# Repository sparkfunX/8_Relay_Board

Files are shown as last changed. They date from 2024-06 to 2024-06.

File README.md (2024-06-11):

SparkX 8 Relay Control Board
========================================

8 Relay Control Board (https://www.sparkfun.com/products/24475)

[*8 Relay Control Board (SPX-24475)*](https://www.sparkfun.com/products/24475)

A simple breakout for controlling 8 relays with logic level signals. Each relay channel is opto-isolated from its corresponding logic input, the inputs accept both 3V and 5V logic, and a status LED on each channel makes it easy to tell at a glance which relay is energized. All LEDs on the board, including the power indicator, are connected through cuttable solder jumpers so they can be disabled if you don't need them. The relays are rated to 5A/250VAC, making them useful for a lot of power control applications.

Repository Contents
-------------------

* **/Hardware** - Eagle design files (.brd, .sch)
* **/Production** - Production panel files (.brd)

License Information
-------------------

This product is _**open source**_! 

Please review the LICENSE.md file for license information. 

If you have any questions or concerns on licensing, please contact technical support on our [SparkFun forums](https://forum.sparkfun.com/viewforum.php?f=152).

Distributed as-is; no warranty is given.

- Your friends at SparkFun.

_<COLLABORATION CREDIT>_

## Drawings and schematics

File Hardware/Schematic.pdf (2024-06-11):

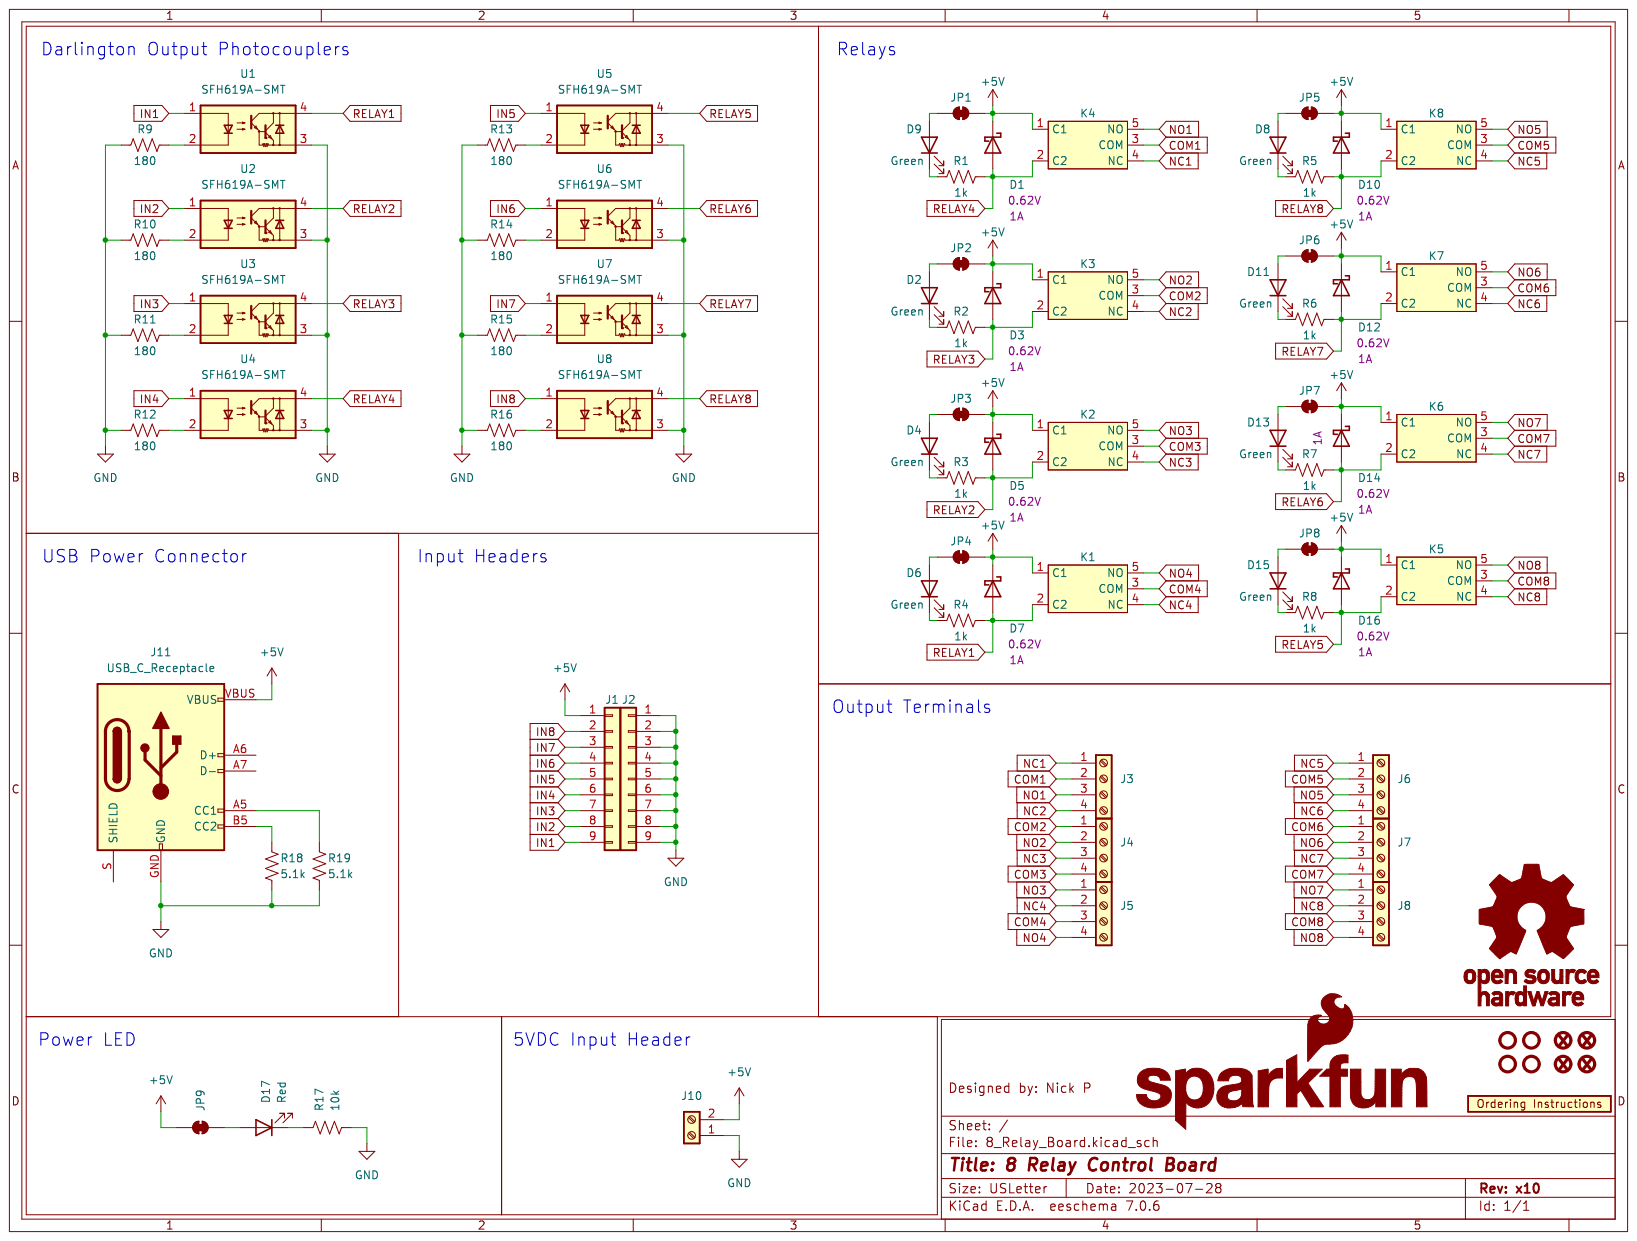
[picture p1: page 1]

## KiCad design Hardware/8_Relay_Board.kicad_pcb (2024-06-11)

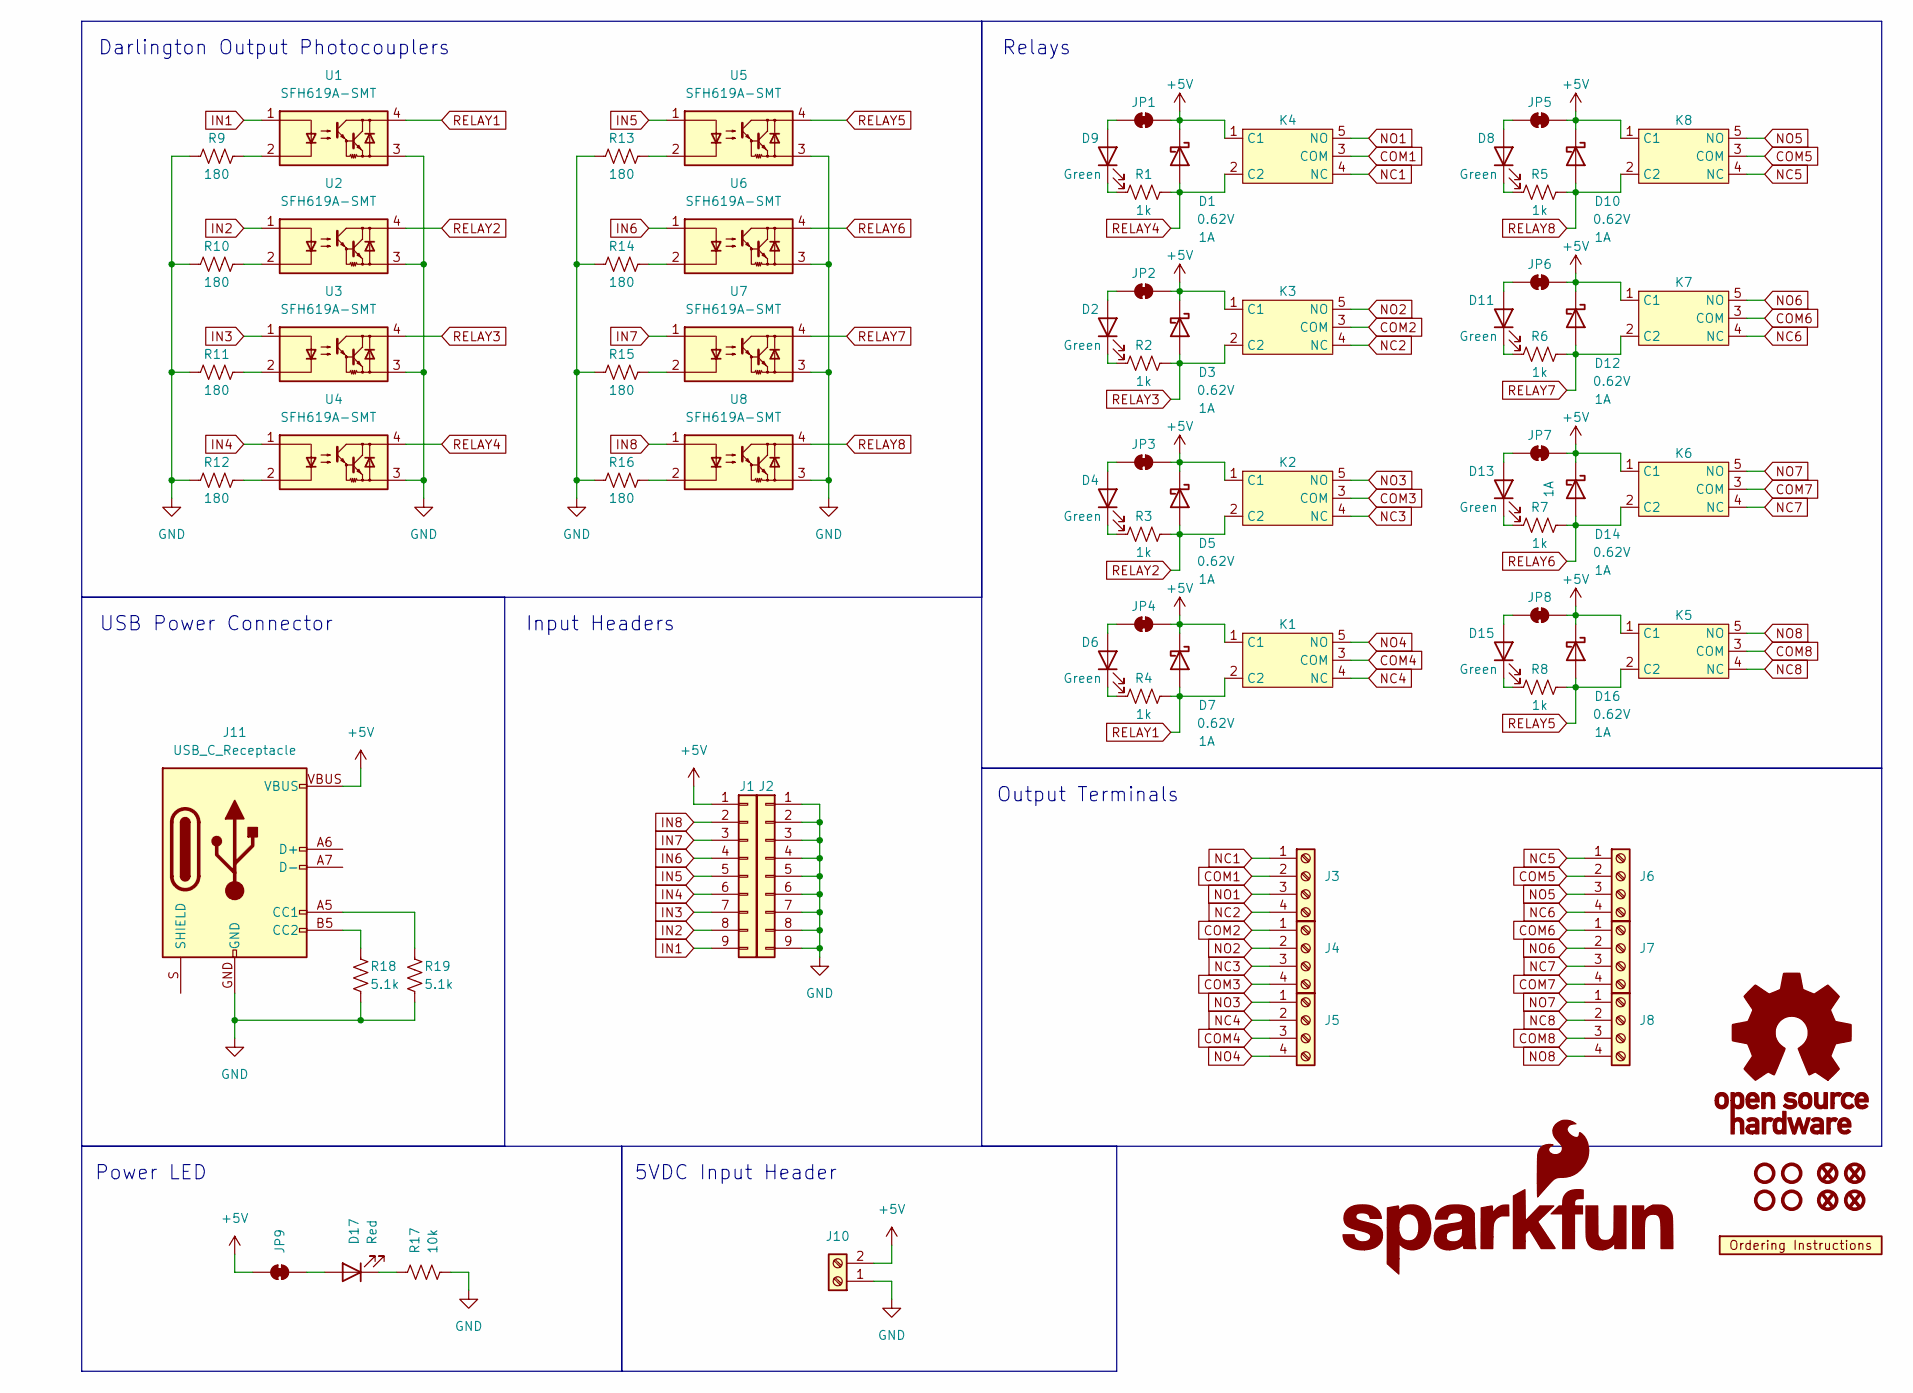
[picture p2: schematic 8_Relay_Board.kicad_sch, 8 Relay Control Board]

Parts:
D1, D3, D5, D7, D10, D12, D16: D_Schottky_1A_23V_0.62V; SOD-323
D2, D4, D6, D8, D9, D11, D13, D15: Green; LED_0603_1608Metric
D14: D_Schottky_1A_23V_0.62V; SOD-323; Reverse Voltage 23V
D17: Red; LED_0603_1608Metric
FID1, FID2, FID3, FID4: Fiducial_0.5; Fiducial_0.5mm_Mask1mm
G1: OSHW_Logo; Creative_Commons_License
G5: SparkFun_Logo; SparkFun_Logo_8mm
J1, J2: Conn_01x09; 1X09
J3, J4, J5, J6, J7, J8: Screw_Terminal_3.5mm_4; SCREWTERMINAL-3.5MM-4
J10: Screw_Terminal_3.5mm_2; SCREWTERMINAL-3.5MM-2
J11: USB_C_Receptacle; USB-C-16P
JP1, JP2, JP3, JP4, JP5, JP6, JP7, JP8, JP9: SMT-JUMPER_2_NC_TRACE_SILK
K1, K2, K3, K4, K5, K6, K7, K8: RELAY-JZC-11F
R1, R2, R3, R4, R5, R6, R7, R8: 1k; R_0603_1608Metric
R9, R10, R11, R12, R13, R14, R15, R16: 180; R_0603_1608Metric
R17: 10k; R_0603_1608Metric
R18, R19: 5.1k; R_0603_1608Metric
ST1, ST2, ST3, ST4: Stand_off; STAND-OFF
U1, U2, U3, U4, U5, U6, U7, U8: SFH619A-SMT; SMDIP4-WIDE
U9: ORDERING_INSTRUCTIONS

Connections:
+5V: D1.C, D3.C, D5.C, D7.C, D10.C, D12.C, D14.C, D16.C, J1.1, J10.2, J11.VBUS, JP1.2 (B), JP2.2 (B), JP3.2 (B), JP4.2 (B), JP5.2 (B), JP6.2 (B), JP7.2 (B), JP8.2 (B), JP9.2 (B), K1.1 (C1), K2.1 (C1), K3.1 (C1), K4.1 (C1), K5.1 (C1), K6.1 (C1), K7.1 (C1), K8.1 (C1)
COM1: J3.2, K4.3 (COM)
COM2: J4.1, K3.3 (COM)
COM3: J4.4, K2.3 (COM)
COM4: J5.3, K1.3 (COM)
COM5: J6.2, K8.3 (COM)
COM6: J7.1, K7.3 (COM)
COM7: J7.4, K6.3 (COM)
COM8: J8.3, K5.3 (COM)
GND: J2.1, J2.2, J2.3, J2.4, J2.5, J2.6, J2.7, J2.8, J2.9, J10.1, J11.GND, R9.1, R10.1, R11.1, R12.1, R13.1, R14.1, R15.1, R16.1, R17.2, R18.2, R19.2, U1.3, U2.3, U3.3, U4.3, U5.3, U6.3, U7.3, U8.3
IN1: J1.9, U1.1
IN2: J1.8, U2.1
IN3: J1.7, U3.1
IN4: J1.6, U4.1
IN5: J1.5, U5.1
IN6: J1.4, U6.1
IN7: J1.3, U7.1
IN8: J1.2, U8.1
NC1: J3.1, K4.4 (NC)
NC2: J3.4, K3.4 (NC)
NC3: J4.3, K2.4 (NC)
NC4: J5.2, K1.4 (NC)
NC5: J6.1, K8.4 (NC)
NC6: J6.4, K7.4 (NC)
NC7: J7.3, K6.4 (NC)
NC8: J8.2, K5.4 (NC)
NO1: J3.3, K4.5 (NO)
NO2: J4.2, K3.5 (NO)
NO3: J5.1, K2.5 (NO)
NO4: J5.4, K1.5 (NO)
NO5: J6.3, K8.5 (NO)
NO6: J7.2, K7.5 (NO)
NO7: J8.1, K6.5 (NO)
NO8: J8.4, K5.5 (NO)
unnamed: D2.2 (A), JP2.1 (A)
unnamed: D2.1 (K), R2.1
unnamed: D4.2 (A), JP3.1 (A)
unnamed: D4.1 (K), R3.1
unnamed: D6.2 (A), JP4.1 (A)
unnamed: D6.1 (K), R4.1
unnamed: D8.2 (A), JP5.1 (A)
unnamed: D8.1 (K), R5.1
unnamed: D9.2 (A), JP1.1 (A)
unnamed: D9.1 (K), R1.1
unnamed: D11.2 (A), JP6.1 (A)
unnamed: D11.1 (K), R6.1
unnamed: D13.2 (A), JP7.1 (A)
unnamed: D13.1 (K), R7.1
unnamed: D15.2 (A), JP8.1 (A)
unnamed: D15.1 (K), R8.1
unnamed: D17.2 (A), JP9.1 (A)
unnamed: D17.1 (K), R17.1
unnamed: J11.A5 (CC1), R19.1
unnamed: J11.B5 (CC2), R18.1
unnamed: J11.A6 (D+), J11.B6 (D+)
unnamed: J11.A7 (D-), J11.B7 (D-)
unnamed: R9.2, U1.2
unnamed: R10.2, U2.2
unnamed: R11.2, U3.2
unnamed: R12.2, U4.2
unnamed: R13.2, U5.2
unnamed: R14.2, U6.2
unnamed: R15.2, U7.2
unnamed: R16.2, U8.2
RELAY1: D7.A, K1.2 (C2), R4.2, U1.4
RELAY2: D5.A, K2.2 (C2), R3.2, U2.4
RELAY3: D3.A, K3.2 (C2), R2.2, U3.4
RELAY4: D1.A, K4.2 (C2), R1.2, U4.4
RELAY5: D16.A, K5.2 (C2), R8.2, U5.4
RELAY6: D14.A, K6.2 (C2), R7.2, U6.4
RELAY7: D12.A, K7.2 (C2), R6.2, U7.4
RELAY8: D10.A, K8.2 (C2), R5.2, U8.4

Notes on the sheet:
Relays
USB Power Connector
Output Terminals
Input Headers
5VDC Input Header
Power LED
Darlington Output Photocouplers

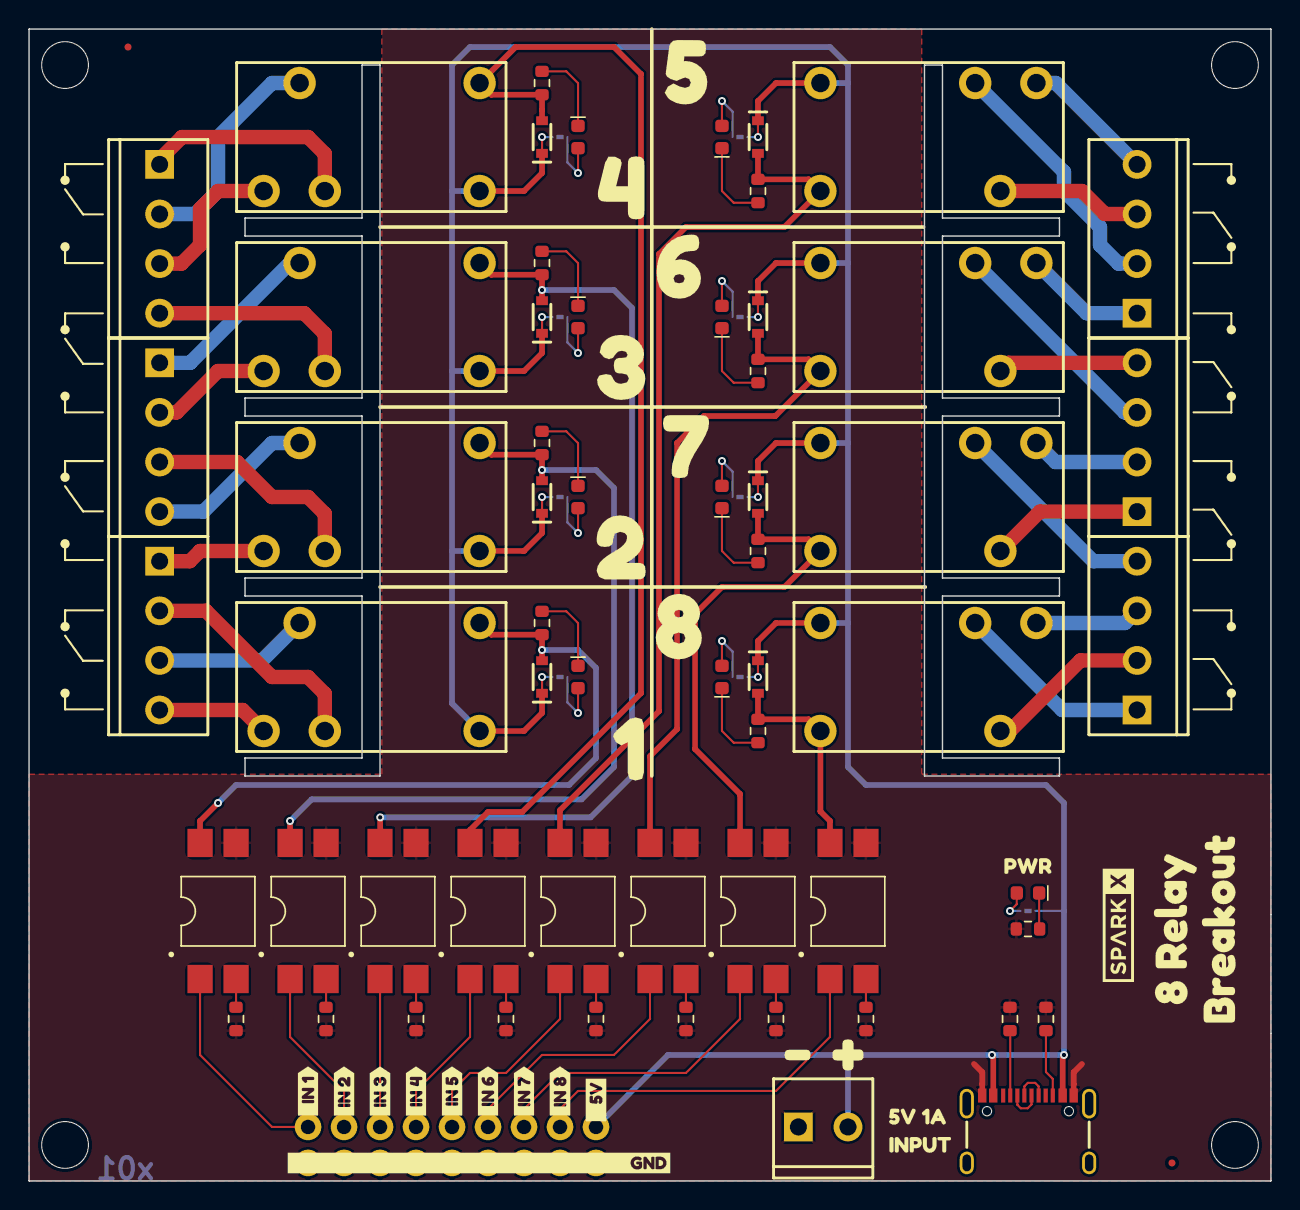
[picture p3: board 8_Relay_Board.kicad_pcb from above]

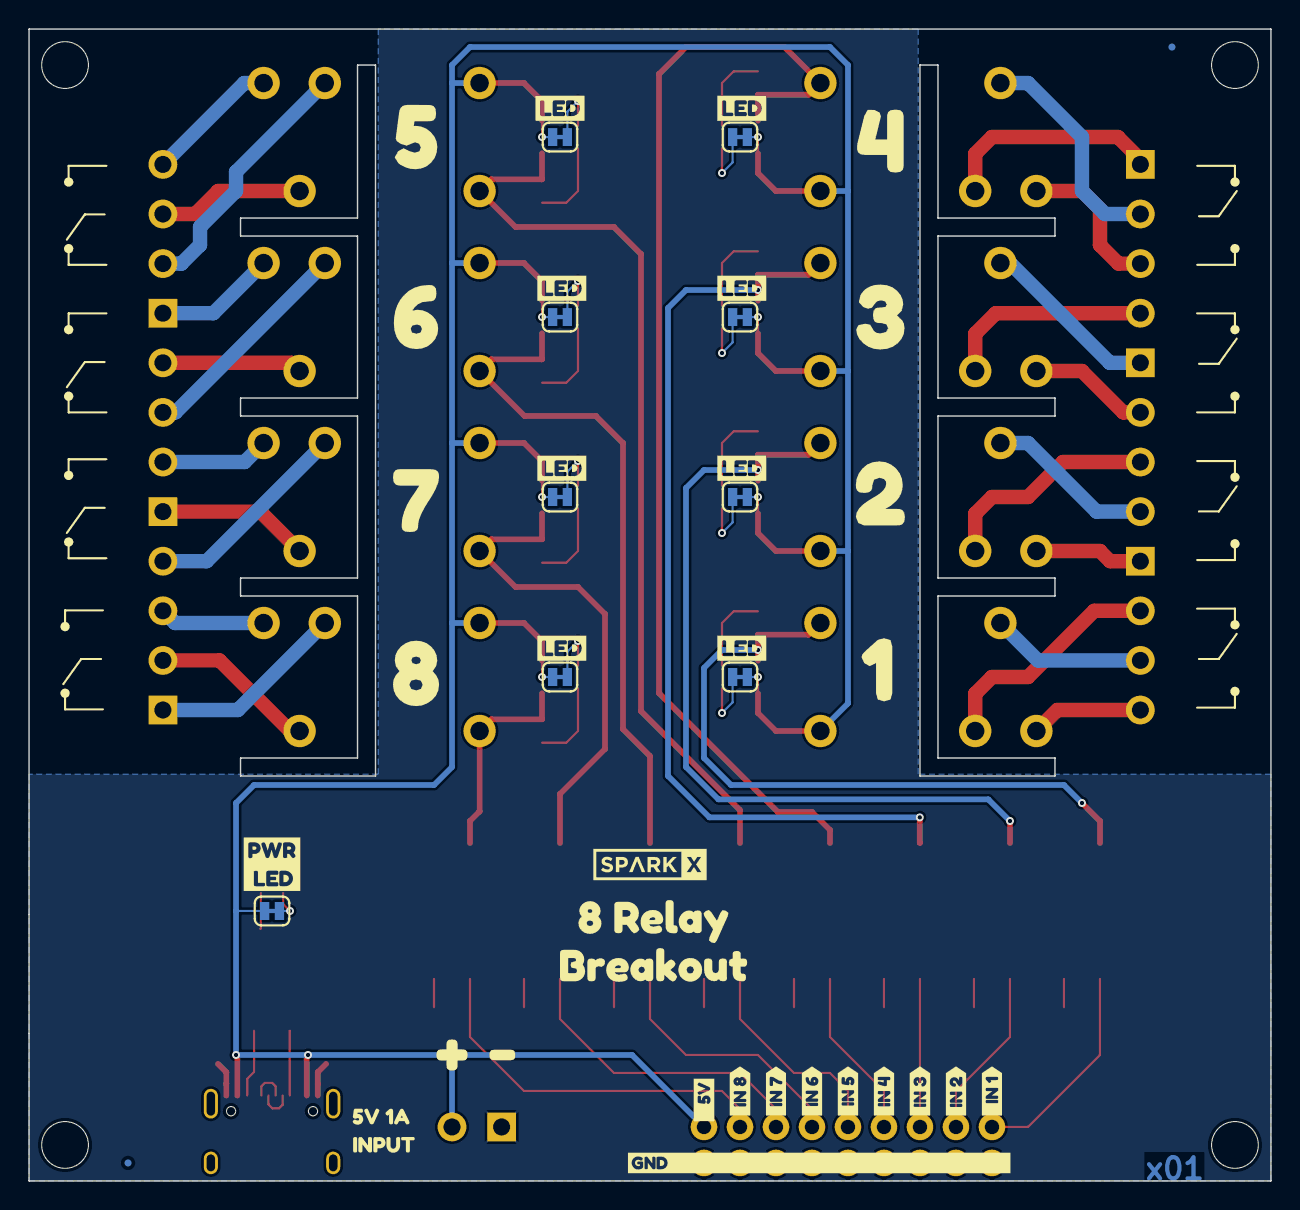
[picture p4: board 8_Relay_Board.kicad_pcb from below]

Board: 4 copper layers, 87.6 x 81.3 mm, 137 parts (43 on the bottom side), 72 nets.

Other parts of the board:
kibuzzard-652EF88E: G***; kibuzzard-652EF88E
kibuzzard-652EF841: G***; kibuzzard-652EF841
kibuzzard-652EF889: G***; kibuzzard-652EF889
kibuzzard-65656C10: G***; kibuzzard-65656C10
kibuzzard-65656C50: G***; kibuzzard-65656C50
kibuzzard-65656C62, kibuzzard-65656C62#2, kibuzzard-65656C62#3, kibuzzard-65656C62#4, kibuzzard-65656C62#5, kibuzzard-65656C62#6, kibuzzard-65656C62#7, kibuzzard-65656C62#8: G***; kibuzzard-65656C62
kibuzzard-652971A7, kibuzzard-652971A7#2: G***; kibuzzard-652971A7
kibuzzard-652971AD, kibuzzard-652971AD#2: G***; kibuzzard-652971AD
kibuzzard-652971B3, kibuzzard-652971B3#2: G***; kibuzzard-652971B3
kibuzzard-652973B2: G***; kibuzzard-652973B2
kibuzzard-652991A0: G***; kibuzzard-652991A0
kibuzzard-652997F8: G***; kibuzzard-652997F8
kibuzzard-6529717D, kibuzzard-6529717D#2: G***; kibuzzard-6529717D
kibuzzard-6529732E, kibuzzard-6529732E#2: G***; kibuzzard-6529732E
kibuzzard-6529733E, kibuzzard-6529733E#2: G***; kibuzzard-6529733E
kibuzzard-6529734A: G***; kibuzzard-6529734A
kibuzzard-6529980A: G***; kibuzzard-6529980A
kibuzzard-65297156, kibuzzard-65297156#2: G***; kibuzzard-65297156
kibuzzard-65297163, kibuzzard-65297163#2: G***; kibuzzard-65297163
kibuzzard-65297189, kibuzzard-65297189#2: G***; kibuzzard-65297189
kibuzzard-65297199, kibuzzard-65297199#2: G***; kibuzzard-65297199
kibuzzard-65297316, kibuzzard-65297316#2: G***; kibuzzard-65297316
kibuzzard-65297321, kibuzzard-65297321#2: G***; kibuzzard-65297321
kibuzzard-65297327, kibuzzard-65297327#2: G***; kibuzzard-65297327
kibuzzard-65297338, kibuzzard-65297338#2: G***; kibuzzard-65297338
kibuzzard-65297343, kibuzzard-65297343#2: G***; kibuzzard-65297343
kibuzzard-65297353, kibuzzard-65297353#2: G***; kibuzzard-65297353
kibuzzard-65297443, kibuzzard-65297443#2: G***; kibuzzard-65297443
kibuzzard-65297450, kibuzzard-65297450#2: G***; kibuzzard-65297450
kibuzzard-65299803: G***; kibuzzard-65299803
kibuzzard-65299816: G***; kibuzzard-65299816

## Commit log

2023-10-09 Schematic and Airwire
    [8_Relay_Board.kicad_pcb, 8_Relay_Board.kicad_sch]
2023-10-10 Close to finishing layout
    [8_Relay_Board.kicad_pcb, 8_Relay_Board.kicad_sch]
2023-10-13 Ready for final review
    [8_Relay_Board.kicad_pcb, 8_Relay_Board.kicad_sch]
2023-12-19 Second pre-release revision
    - Add isolation under relays
    [8_Relay_Board.kicad_pcb, 8_Relay_Board.kicad_sch]
2024-06-11 Add docs zip and schematic pdf
    [8_Relay_Board.kicad_pcb]

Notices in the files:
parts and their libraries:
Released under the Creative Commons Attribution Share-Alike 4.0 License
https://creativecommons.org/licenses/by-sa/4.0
